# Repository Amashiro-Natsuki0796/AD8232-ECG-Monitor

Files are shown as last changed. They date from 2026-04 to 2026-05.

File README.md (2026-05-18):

# AD8232-ECG-Monitor

Real-time ECG monitoring system using AD8232 sensor, ESP8266 microcontroller, Raspberry Pi Zero/Zero W, and MHS3.5 LCD display.

# Project Background:
Originally this was my personal hobby project, and I made a simplified version to enter in a competition. However, a few days later a friend who was approaching her college entrance exam told me she had symptoms resembling panic attacks, with heart palpitations, shortness of breath, and feelings of impending doom. Since she lived alone, I worked continuously for 15 hours to add UI interaction and remote monitoring features, hoping to help her and hoping I could face my former self with a clear conscience.

## Example ECG Waveforms
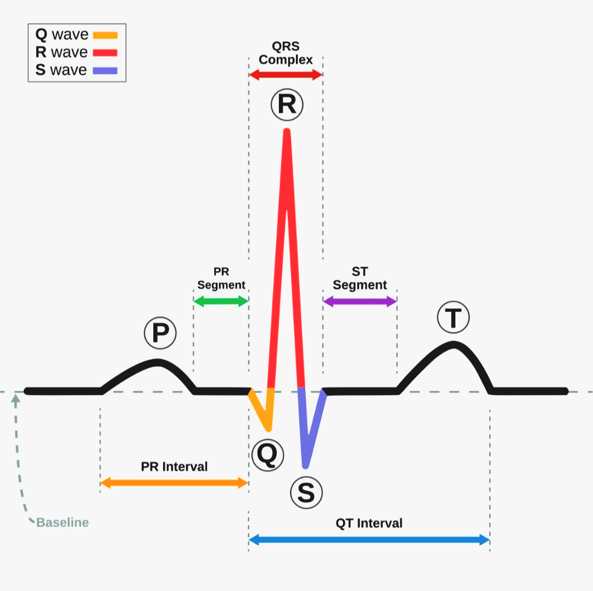
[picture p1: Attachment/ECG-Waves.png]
ECG Waves


## Hardware Components
- AD8232 ECG Sensor Module
- ESP8266 Development Board
- Raspberry Pi Zero/Zero W (Please use the Zero W version if you want to use the network remote monitoring feature)
- MHS3.5 LCD Display (480x320 resolution)
- LC filtering module (0-25V)

## Electrode Placement Diagram
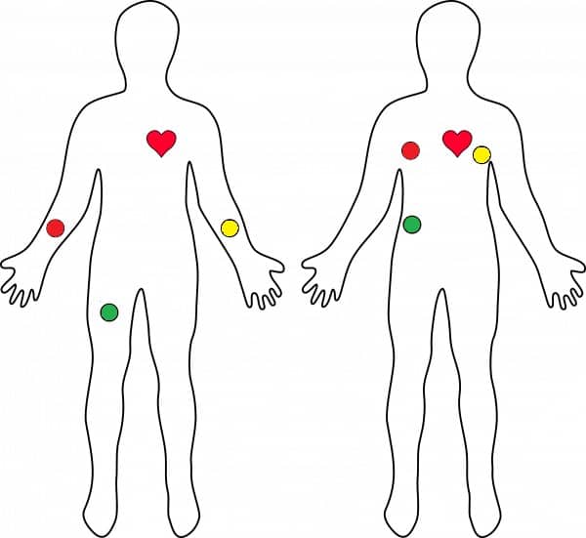
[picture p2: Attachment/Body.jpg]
Electrode Placement


## Build and Deployment Guide

### 1. ESP8266 Setup
Upload the `ESP8266.ino` file to your ESP8266 board using Arduino IDE:
- Open `ESP8266.ino` in Arduino IDE
- Select appropriate board settings for your ESP8266
- Compile and upload the program

### 1.1 Using Remote Monitoring Feature
To use the remote monitoring feature, you need to configure your Raspberry Pi to connect to your WiFi network, and register a free account at [Sakura Frp](https://www.natfrp.com) and create a TCP tunnel.

### 2. Raspberry Pi Zero Setup
Connect your Raspberry Pi Zero/Zero W to the MHS3.5 LCD display and ensure proper wiring between ESP8266 and Pi:
- Connect the TX pin of ESP8266 to the RX pin (GPIO 15) of Raspberry Pi UART
- Ensure common ground connection between ESP8266 and Raspberry Pi
- MHS3.5 LCD connects to Raspberry Pi Zero via GPIO pins
##### As shown in the diagram below:
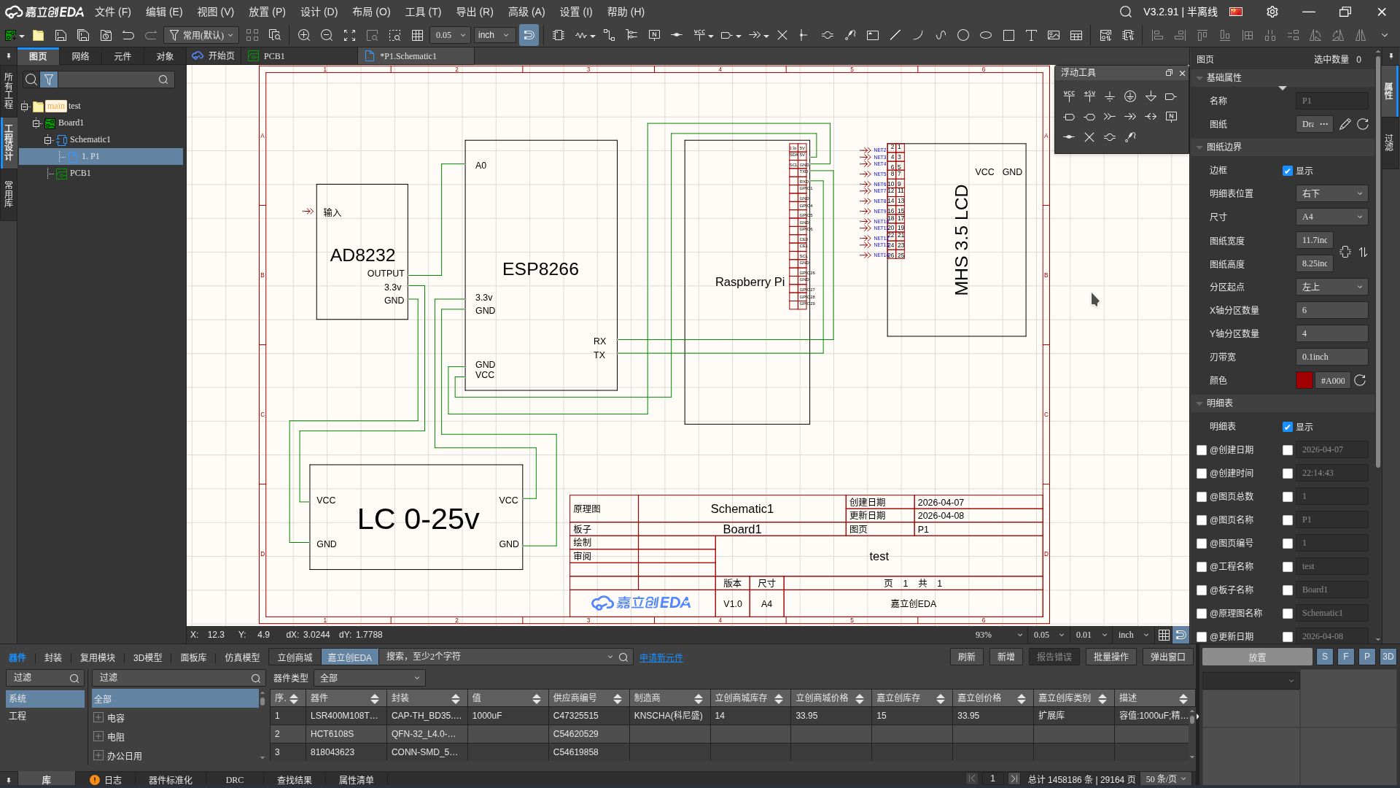
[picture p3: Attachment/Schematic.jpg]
Wiring Diagram


### 2.1 LCD Driver Installation
If using MHS3.5 LCD screen, install the corresponding drivers:
```bash
# Download LCD-show driver
git clone https://github.com/goodtft/LCD-show.git
chmod -R 755 LCD-show
cd LCD-show/
sudo ./MHS35-show
```

### 3. Environment Preparation
```bash
# Clone the repository on Target side:
git clone https://github.com/Amashiro-Natsuki0796/AD8232-ECG-Monitor.git
cd AD8232-ECG-Monitor

# Install dependencies
sudo apt-get update
sudo apt-get install build-essential nano gcc
# Configure wireless network connection
sudo raspi-config
```

### 4. Modify and Compile
```bash
# On Host side run:
cd Sakura-Frp/
./frpc
# Login to your account

# On Target side run:
cd AD8232-ECG-Monitor/
nano Main.c # Modify SERVER_IP to your IP address
make -j$(nproc)
sudo ./Main
```

### 5. Auto-start Service (Optional)
To automatically run the ECG monitor on startup:
```bash
# Copy service file to systemd
sudo cp ECG.service /etc/systemd/system/

# Enable and start the service
sudo systemctl enable ECG.service
sudo systemctl start ECG.service
```

## 3D Printed Enclosure Models
We provide 3D models for housing the electronics in a dedicated enclosure:
- Shell.STL - Main housing
- Bottom.STL - Bottom cover
- Stent.STL - Internal support structure

These SolidWorks models are located in the `Shell Model` directory and can be 3D printed to create an enclosure for the ECG monitor.

## Demonstration Video
Watch the demonstration videos to see the ECG monitor in action:

[Development Phase](Attachment/ENG.mp4)
[Demo Video](Attachment/Demo.mp4)

## Demo Screenshots
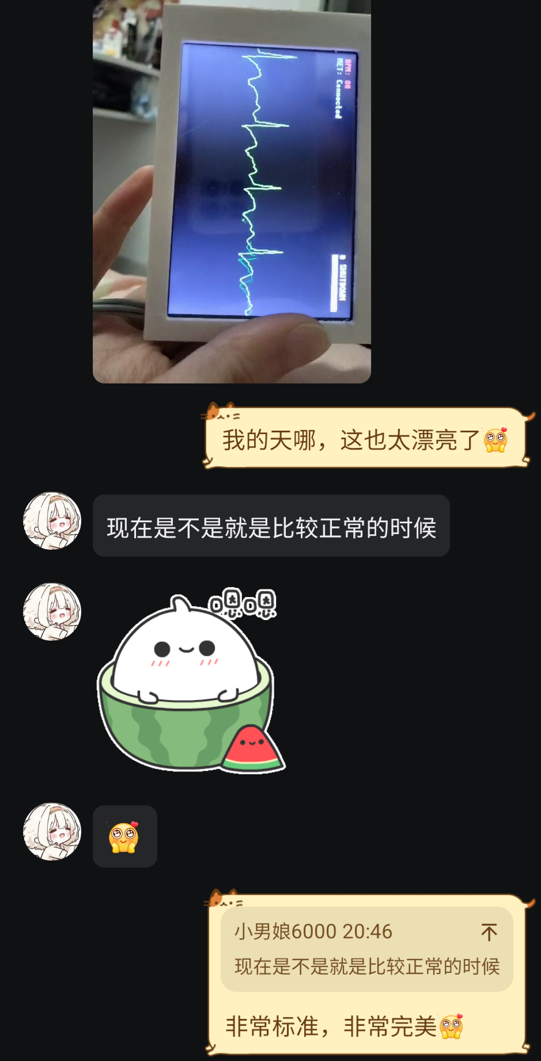
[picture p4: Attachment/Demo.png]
Log

Client

## Alternative Display Solutions
As an alternative to PC-side visualization, Python-based plotting tools are provided:

Remote monitoring: 
`Attachment/ECG_network_plotter.py`

ESP8266 serial plotting: 
`Attachment/ECG_serial_plotter.py`

Host-side simulation data sending: 
`Attachment/ECG_simulator.py`

# Disclaimer:
This project is for learning and reference purposes only and cannot be used in professional medical fields. The author does not assume any responsibility if users violate the agreement.

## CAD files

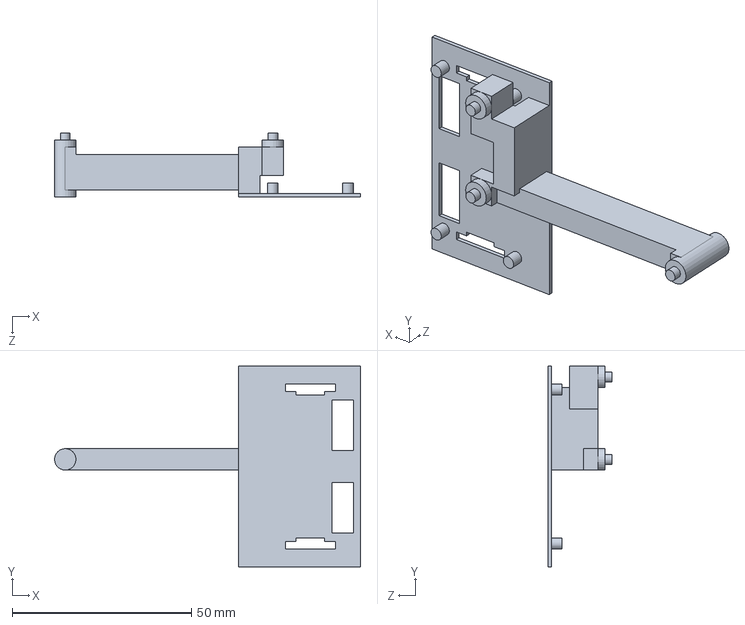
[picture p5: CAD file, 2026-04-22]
Shell Model/Stent.SLDPRT
85.4 x 56.0 x 18.0 mm

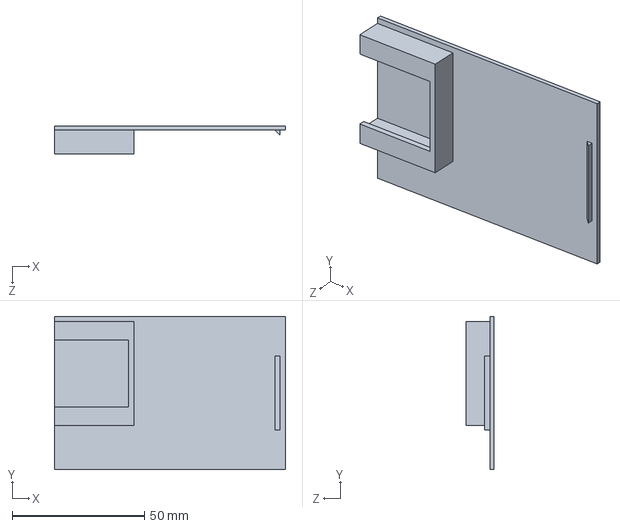
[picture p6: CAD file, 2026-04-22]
Shell Model/Bottom.SLDPRT
87.4 x 58.0 x 10.5 mm

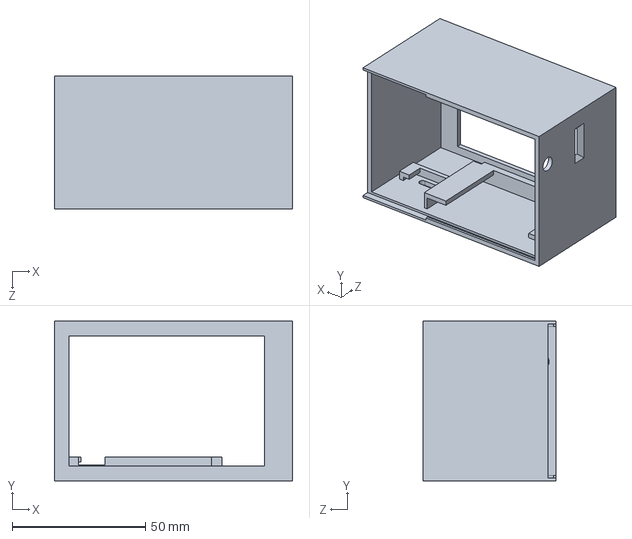
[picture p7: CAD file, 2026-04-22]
Shell Model/Shell.SLDPRT
89.4 x 60.0 x 50.0 mm

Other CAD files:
Shell Model/Bottom.STL
Shell Model/Shell.STL
Shell Model/Stent.STL

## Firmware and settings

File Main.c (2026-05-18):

#define _GNU_SOURCE
#include <stdio.h>
#include <stdlib.h>
#include <string.h>
#include <unistd.h>
#include <fcntl.h>
#include <math.h>
#include <termios.h>
#include <time.h>
#include <sys/time.h>
#include <sys/ioctl.h>
#include <sys/mman.h>
#include <sys/stat.h>
#include <linux/fb.h>
#include <errno.h>
#include <stdint.h>
#include <sched.h>
#include <sys/socket.h>
#include <netinet/in.h>
#include <arpa/inet.h>
#include <netdb.h>
#include <signal.h>
#include <linux/input.h>
#include <linux/uinput.h>

#ifndef M_PI
#define M_PI 3.14159265358979323846
#endif

#define SR 250.0
#define MAX_DP 750
#define PORT "/dev/ttyS0"
#define BR B115200
#define BS 1024

// 显示参数 - 树莓派Zero 480x320 分辨率 16bpp
#define SCREEN_WIDTH 480
#define SCREEN_HEIGHT 320
#define BYTES_PER_PIXEL 2  // 16bpp = 2 bytes per pixel

// 网络参数
#define SERVER_IP "**.***.***.***"
#define SERVER_PORT 23956
int network_socket = -1;
time_t last_connect_attempt = 0;
const int RECONNECT_INTERVAL = 5; // 重连间隔5秒

// 数据缓冲区，每0.5秒发送一次数据
#define NETWORK_BUFFER_SIZE 2048
char network_buffer[NETWORK_BUFFER_SIZE]; // 缓冲区用于存储0.5秒的数据
int buffer_pos = 0;
struct timeval last_send_time; // 使用timeval记录精确时间
double SEND_INTERVAL = 0.5; // 每0.5秒发送一次数据
int consecutive_send_failures = 0; // 连续发送失败次数
const int MAX_CONSECUTIVE_FAILURES = 3; // 最大连续失败次数后重置连接

// 触摸屏参数
#define TOUCH_DEVICE "/dev/input/event0"
int touch_fd = -1;
int paused = 0; // 暂停标志
// 关机功能相关变量
int touch_down = 0; // 触摸按下状态
struct timeval touch_start_time; // 触摸开始时间
int shutdown_triggered = 0; // 关机是否已触发

// 滤波器参数
double b_h[3], a_h[3], z_h[2];
double f_d[MAX_DP], ma_b[5];
int dc = 0, mc = 0;

// BPM计算相关变量
double last_peak_time = 0.0;
double current_heart_rate = 0.0;
double signal_peaks[50];  // 存储最近的峰值
int peak_count = 0;
double rr_intervals[50];  // 存储RR间期
int rr_count = 0;
double dynamic_threshold = 0.1;  // 动态阈值
double peak_hold = 0.0;          // 峰值保持
double last_voltage = 0.0;       // 上次电压值用于检测下降沿
int refractory_period_counter = 0; // 不应期计数器
const int REFRACTORY_PERIOD = 50;  // 不应期（采样点数）
double start_time = 0.0;           // 开始时间戳

// 函数声明
void draw_pixel(int x, int y, uint16_t color);

// framebuffer相关变量
int fb_fd = -1;
char *fb_ptr = NULL;
struct fb_var_screeninfo vinfo;
struct fb_fix_screeninfo finfo;

// 字符大小
#define CHAR_WIDTH 8
#define CHAR_HEIGHT 12

// ASCII字符字模数据 (简化版，只包含数字和基本字符)
const unsigned char font_data[96][12] = {
    {0x00,0x00,0x00,0x00,0x00,0x00,0x00,0x00,0x00,0x00,0x00,0x00}, // ' ' (32)
    {0x10,0x10,0x10,0x10,0x10,0x00,0x10,0x00,0x10,0x00,0x00,0x00}, // '!' (33)
    {0x28,0x28,0x00,0x00,0x00,0x00,0x00,0x00,0x00,0x00,0x00,0x00}, // '"' (34)
    {0x00,0x00,0x6C,0x6C,0xFE,0x6C,0x6C,0x6C,0xFE,0x6C,0x6C,0x00}, // '#' (35)
    {0x18,0x3C,0x66,0x24,0x18,0x3C,0x66,0x66,0x3C,0x18,0x00,0x00}, // '$' (36)
    {0x00,0xC6,0xCC,0x18,0x30,0x60,0xC0,0x66,0x3C,0x00,0x00,0x00}, // '%' (37)
    {0x38,0x6C,0x6C,0x38,0x76,0xDC,0xCC,0xCC,0x76,0x00,0x00,0x00}, // '&' (38)
    {0x10,0x10,0x20,0x00,0x00,0x00,0x00,0x00,0x00,0x00,0x00,0x00}, // ''' (39)
    {0x0C,0x18,0x30,0x30,0x30,0x30,0x30,0x30,0x18,0x0C,0x00,0x00}, // '(' (40)
    {0x30,0x18,0x0C,0x0C,0x0C,0x0C,0x0C,0x0C,0x18,0x30,0x00,0x00}, // ')' (41)
    {0x00,0x00,0x66,0x3C,0xFF,0x3C,0x66,0x00,0x00,0x00,0x00,0x00}, // '*' (42)
    {0x00,0x00,0x10,0x10,0x7C,0x10,0x10,0x00,0x00,0x00,0x00,0x00}, // '+' (43)
    {0x00,0x00,0x00,0x00,0x00,0x00,0x00,0x00,0x18,0x18,0x30,0x00}, // ',' (44)
    {0x00,0x00,0x00,0x00,0x7C,0x00,0x00,0x00,0x00,0x00,0x00,0x00}, // '-' (45)
    {0x00,0x00,0x00,0x00,0x00,0x00,0x00,0x00,0x18,0x18,0x00,0x00}, // '.' (46)
    {0x00,0x02,0x06,0x0C,0x18,0x30,0x60,0xC0,0x80,0x00,0x00,0x00}, // '/' (47)
    {0x38,0x6C,0xC6,0xE6,0xF6,0xDE,0xCE,0xC6,0x6C,0x38,0x00,0x00}, // '0' (48)
    {0x18,0x38,0x78,0x18,0x18,0x18,0x18,0x18,0x18,0x7E,0x00,0x00}, // '1' (49)
    {0x3C,0x66,0x06,0x06,0x0C,0x18,0x30,0x60,0x60,0x7E,0x00,0x00}, // '2' (50)
    {0x3C,0x66,0x06,0x06,0x1C,0x06,0x06,0x06,0x66,0x3C,0x00,0x00}, // '3' (51)
    {0x06,0x0E,0x1E,0x66,0x66,0x66,0x7F,0x06,0x06,0x06,0x00,0x00}, // '4' (52)
    {0x7E,0x60,0x60,0x60,0x7C,0x06,0x06,0x06,0x66,0x3C,0x00,0x00}, // '5' (53)
    {0x1C,0x30,0x60,0x60,0x7C,0x66,0x66,0x66,0x66,0x3C,0x00,0x00}, // '6' (54)
    {0x7E,0x66,0x06,0x06,0x0C,0x18,0x18,0x18,0x18,0x18,0x00,0x00}, // '7' (55)
    {0x3C,0x66,0x66,0x66,0x3C,0x66,0x66,0x66,0x66,0x3C,0x00,0x00}, // '8' (56)
    {0x3C,0x66,0x66,0x66,0x66,0x3E,0x06,0x06,0x66,0x3C,0x00,0x00}, // '9' (57)
    {0x00,0x00,0x18,0x18,0x00,0x00,0x00,0x18,0x18,0x00,0x00,0x00}, // ':' (58)
    {0x00,0x00,0x18,0x18,0x00,0x00,0x00,0x18,0x18,0x30,0x00,0x00}, // ';' (59)
    {0x0C,0x18,0x30,0x60,0xC0,0x60,0x30,0x18,0x0C,0x00,0x00,0x00}, // '<' (60)
    {0x00,0x00,0x00,0xFE,0x00,0x00,0xFE,0x00,0x00,0x00,0x00,0x00}, // '=' (61)
    {0x60,0x30,0x18,0x0C,0x06,0x0C,0x18,0x30,0x60,0x00,0x00,0x00}, // '>' (62)
    {0x3C,0x66,0x06,0x0C,0x18,0x18,0x18,0x00,0x18,0x18,0x00,0x00}, // '?' (63)
    {0x38,0x4C,0xBA,0xBA,0xB8,0xB0,0xB0,0xB0,0x6C,0x38,0x00,0x00}, // '@' (64)
    {0x10,0x38,0x6C,0xC6,0xC6,0xFE,0xC6,0xC6,0xC6,0xC6,0x00,0x00}, // 'A' (65)
    {0x7C,0x66,0x66,0x66,0x7C,0x66,0x66,0x66,0x66,0x7C,0x00,0x00}, // 'B' (66)
    {0x3C,0x66,0x60,0x60,0x60,0x60,0x60,0x60,0x66,0x3C,0x00,0x00}, // 'C' (67)
    {0x78,0x6C,0x66,0x66,0x66,0x66,0x66,0x66,0x6C,0x78,0x00,0x00}, // 'D' (68)
    {0x7E,0x60,0x60,0x60,0x7C,0x60,0x60,0x60,0x60,0x7E,0x00,0x00}, // 'E' (69)
    {0x7E,0x60,0x60,0x60,0x7C,0x60,0x60,0x60,0x60,0x60,0x00,0x00}, // 'F' (70)
    {0x3C,0x66,0x06,0x06,0x06,0x7E,0x66,0x66,0x66,0x3C,0x00,0x00}, // 'G' (71)
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
    {0x00,0x00,0x00,0x00,0x00,0x00,0x00,0x00,0x00,0x00,0x00,0x00}  // DEL (127)
};

// 函数声明
void add_to_network_buffer(double value, double timestamp);
void flush_network_buffer();
void check_and_reconnect();
int init_touchscreen();
void handle_touch_events();

// 将RGB888转换为RGB565
uint16_t rgb888_to_rgb565(int r, int g, int b) {
    r = (r >> 3) & 0x1F;  // 8位红转5位
    g = (g >> 2) & 0x3F;  // 8位绿转6位
    b = (b >> 3) & 0x1F;  // 8位蓝转5位
    return (r << 11) | (g << 5) | b;
}

// 在framebuffer上绘制字符
void draw_char(int x, int y, char c, uint16_t color) {
    if (c < 32 || c > 127) return; // 只支持ASCII 32-127
    
    int char_index = c - 32;
    
    for (int row = 0; row < CHAR_HEIGHT; row++) {
        unsigned char byte = font_data[char_index][row];
        for (int col = 0; col < 8; col++) {
            if ((byte >> (7 - col)) & 1) {
                draw_pixel(x + col, y + row, color);
            }
        }
    }
}

// 在framebuffer上绘制字符串
void draw_string(int x, int y, const char* str, uint16_t color) {
    int orig_x = x;
    while (*str) {
        if (*str == '\n') {
            y += CHAR_HEIGHT + 2;
            x = orig_x;
        } else {
            draw_char(x, y, *str, color);
            x += CHAR_WIDTH;
        }
        str++;
    }
}

// 初始化framebuffer
int init_framebuffer() {
    fb_fd = open("/dev/fb1", O_RDWR);
    if (fb_fd == -1) {
        fb_fd = open("/dev/fb0", O_RDWR);
        if (fb_fd == -1) {
            return -1;
        }
    }
    
    if (ioctl(fb_fd, FBIOGET_FSCREENINFO, &finfo)) {
        close(fb_fd);
        return -1;
    }
    
    if (ioctl(fb_fd, FBIOGET_VSCREENINFO, &vinfo)) {
        close(fb_fd);
        return -1;
    }
    
    // 映射framebuffer到内存
    fb_ptr = (char *)mmap(0, 
                         finfo.smem_len, 
                         PROT_READ | PROT_WRITE, 
                         MAP_SHARED, 
                         fb_fd, 
                         0);
    
    if (fb_ptr == (char *)-1) {
        close(fb_fd);
        return -1;
    }
    
    return 0;
}

// 初始化触摸屏
int init_touchscreen() {
    touch_fd = open(TOUCH_DEVICE, O_RDONLY | O_NONBLOCK);
    if (touch_fd < 0) {
        return -1;
    }
    return 0;
}

// 处理触摸事件
void handle_touch_events() {
    if (touch_fd < 0) {
        return;
    }
    
    // Linux输入事件结构体
    struct input_event ev;
    ssize_t n;
    
    // 读取所有可用的触摸事件
    while ((n = read(touch_fd, &ev, sizeof(struct input_event))) > 0) {
        // 检查是否是按键事件（按下或释放）
        if (ev.type == EV_KEY && ev.code == BTN_TOUCH) {
            if (ev.value == 1) { // 按下触摸屏
                touch_down = 1;
                gettimeofday(&touch_start_time, NULL); // 记录按下时间
                shutdown_triggered = 0; // 重置关机触发状态
            } else if (ev.value == 0) { // 抬起触摸屏
                touch_down = 0;
                // 检查触摸持续时间，如果小于3秒则切换暂停状态
                struct timeval current_time;
                gettimeofday(&current_time, NULL);
                double elapsed = (current_time.tv_sec - touch_start_time.tv_sec) + 
                                (current_time.tv_usec - touch_start_time.tv_usec) / 1000000.0;
                
                // 如果触摸时间少于0.3秒且未触发关机，则切换暂停状态
                if (elapsed < 0.3 && !shutdown_triggered) {
                    paused = !paused; // 切换暂停状态
                }
            }
        }
    }
}

// 检查长按是否需要关机
void check_long_press_shutdown() {
    if (touch_down && !shutdown_triggered) {
        struct timeval current_time;
        gettimeofday(&current_time, NULL);
        
        double elapsed = (current_time.tv_sec - touch_start_time.tv_sec) + 
                        (current_time.tv_usec - touch_start_time.tv_usec) / 1000000.0;
        
        if (elapsed >= 3.0) { // 长按3秒触发关机
            shutdown_triggered = 1;
            system("sudo shutdown -h now"); // 执行关机命令
        }
    }
}

// 绘制关机进度条
void draw_shutdown_progress() {
    struct timeval current_time;
    gettimeofday(&current_time, NULL);
    
    double elapsed = 0;
    int is_counting = 0;
    
    // 如果正在触摸且未触发关机，则计算长按时间
    if (touch_down && !shutdown_triggered) {
        elapsed = (current_time.tv_sec - touch_start_time.tv_sec) + 
                (current_time.tv_usec - touch_start_time.tv_usec) / 1000000.0;
        is_counting = 1;
    }
    
    // 在右上角绘制进度条，与NET状态底部对齐
    int bar_width = (int)(fmin(elapsed / 3.0, 1.0) * 100); // 最大宽度100像素
    int bar_height = 10; // 高度10像素
    int bar_x = SCREEN_WIDTH - 110; // 右边距110像素
    int bar_y = 25; // 上边距25像素，与NET状态Y坐标相同，这样底部对齐（NET状态高度约12像素，进度条高度10像素）
    
    // 绘制进度条背景（灰色）
    uint16_t gray_color = rgb888_to_rgb565(128, 128, 128);
    for (int y = bar_y; y < bar_y + bar_height; y++) {
        for (int x = bar_x; x < bar_x + 100; x++) {
            draw_pixel(x, y, gray_color);
        }
    }
    
    // 绘制进度（紫色）
    uint16_t purple_color = rgb888_to_rgb565(128, 0, 128);
    for (int y = bar_y; y < bar_y + bar_height; y++) {
        for (int x = bar_x; x < bar_x + bar_width; x++) {
            if (is_counting) { // 只有在计时过程中才显示进度
                draw_pixel(x, y, purple_color);
            }
        }
    }
    
    // 绘制"Shutdown"文字
    uint16_t white_color = rgb888_to_rgb565(255, 255, 255);
    draw_string(bar_x, bar_y - 15, "# SHUTDOWN", white_color); // 文字位置也要相应调整
}

// 清屏为黑色
void clear_screen() {
    if (fb_ptr && (vinfo.xres * vinfo.yres * BYTES_PER_PIXEL <= finfo.smem_len)) {
        memset(fb_ptr, 0, vinfo.xres * vinfo.yres * BYTES_PER_PIXEL);
    }
}

// 隐藏光标
void hide_cursor() {
    system("setterm -cursor off 2>/dev/null || true");
}

// 显示光标
void show_cursor() {
    system("setterm -cursor on 2>/dev/null || true");
}

// 在framebuffer上绘制像素点
void draw_pixel(int x, int y, uint16_t color) {
    if (x >= 0 && (unsigned int)x < vinfo.xres && y >= 0 && (unsigned int)y < vinfo.yres) {
        long location = (x + vinfo.xoffset) * BYTES_PER_PIXEL + (y + vinfo.yoffset) * finfo.line_length;
        *(uint16_t*)(fb_ptr + location) = color;
    }
}

// 使用Bresenham算法绘制直线
void draw_line(int x0, int y0, int x1, int y1, uint16_t color) {
    int dx = abs(x1-x0), sx = x0<x1 ? 1 : -1;
    int dy = abs(y1-y0), sy = y0<y1 ? 1 : -1; 
    int err = (dx>dy ? dx : -dy)/2, e2;
 
    for(;;){
        draw_pixel(x0, y0, color);
        if (x0==x1 && y0==y1) break;
        e2 = err;
        if (e2 >-dx) { err -= dy; x0 += sx; }
        if (e2 < dy) { err += dx; y0 += sy; }
    }
}

// 绘制ECG波形到framebuffer
void draw_ecg_waveform() {
    if (!fb_ptr) return;
    
    // 只清除波形区域，保持背景黑色
    // 计算波形显示区域的行数，仅清空这部分
    int start_row = 0;
    unsigned int end_row = vinfo.yres;
    
    // 清除波形区域（设为黑色）
    for (unsigned int y = start_row; y < end_row; y++) {
        for (unsigned int x = 0; x < vinfo.xres; x++) {
            long location = (x + vinfo.xoffset) * BYTES_PER_PIXEL + (y + vinfo.yoffset) * finfo.line_length;
            if (location < (long)finfo.smem_len) {
                *(uint16_t*)(fb_ptr + location) = 0x0000; // 黑色
            }
        }
    }

    if (dc > 1) {
        uint16_t green_color = rgb888_to_rgb565(0, 255, 0);  // 绿色
        
        int ds = (dc > MAX_DP) ? dc - MAX_DP : 0;
        int dco = dc - ds;
        
        if (dco > 1) {
            double dd[MAX_DP];
            for (int i = ds; i < dc; i++) dd[i - ds] = f_d[i];
            
            double min_y = dd[0], max_y = dd[0];
            for (int i = 0; i < dco; i++) {
                if (dd[i] < min_y) min_y = dd[i];
                if (dd[i] > max_y) max_y = dd[i];
            }
            
            double cy = (min_y + max_y) / 2.0;
            double ry = max_y - min_y;
            if (ry < 2.0) ry = 2.0;
            
            double ymin = cy - ry;
            double ymax = cy + ry;
            
            // 绘制波形线
            for (int i = 1; i < dco; i++) {
                int x1 = (i - 1) * vinfo.xres / dco;
                int x2 = i * vinfo.xres / dco;
                int y1 = (int)((dd[i-1] - ymin) / (ymax - ymin) * vinfo.yres);
                int y2 = (int)((dd[i] - ymin) / (ymax - ymin) * vinfo.yres);
                
                // 转换Y坐标（因为framebuffer的原点在左上角，而我们的数据是正向的）
                y1 = vinfo.yres - y1;
                y2 = vinfo.yres - y2;
                
                draw_line(x1, y1, x2, y2, green_color);
            }
        }
    }
    
    // 绘制BPM数值
    uint16_t red_color = rgb888_to_rgb565(255, 0, 0);  // 红色
    char bpm_text[20];
    snprintf(bpm_text, sizeof(bpm_text), "BPM: %.0f", current_heart_rate);
    draw_string(10, 10, bpm_text, red_color);  // 在左上角显示BPM
    
    // 绘制网络连接状态
    uint16_t net_status_color;
    char net_status_text[30];
    if (network_socket >= 0) {
        net_status_color = rgb888_to_rgb565(173, 216, 230);  // 浅蓝色
        strcpy(net_status_text, "NET: Connected");
    } else {
        net_status_color = rgb888_to_rgb565(255, 165, 0);     // 橙色
        strcpy(net_status_text, "NET: Disconnected");
    }
    draw_string(10, 25, net_status_text, net_status_color);  // 在BPM下方显示网络状态
}

void init_filter() {
    double nq = 0.5 * SR, Wn = 0.5 / nq;
    double a = tan(M_PI * Wn), as = a * a, f = as + 2*a + 1;
    b_h[0] = 1.0/f; b_h[1] = -2.0/f; b_h[2] = 1.0/f;
    a_h[0] = 1.0; a_h[1] = (2.0 * (as - 1))/f; a_h[2] = (as - 2*a + 1)/f;
    z_h[0] = 0.0; z_h[1] = 0.0;
}

double filter(double in) {
    double out = b_h[0] * in + z_h[0];
    z_h[0] = b_h[1] * in - a_h[1] * out + z_h[1];
    z_h[1] = b_h[2] * in - a_h[2] * out;
    return out;
}

int open_port(const char* p) {
    int fd = open(p, O_RDWR | O_NOCTTY | O_SYNC);
    if (fd < 0) { 
        return -1; 
    }
    
    struct termios tty;
    memset(&tty, 0, sizeof(tty));
    if (tcgetattr(fd, &tty) != 0) { 
        close(fd);
        return -1; 
    }
    
    cfsetospeed(&tty, BR);
    cfsetispeed(&tty, BR);
    tty.c_cflag |= (CLOCAL | CREAD);
    tty.c_cflag &= ~CSIZE;
    tty.c_cflag |= CS8;
    tty.c_cflag &= ~PARENB;
    tty.c_cflag &= ~CSTOPB;
    #ifdef CRTSCTS
    tty.c_cflag &= ~CRTSCTS;
    #else
    tty.c_cflag &= ~020000000000;
    #endif
    tty.c_iflag &= ~(IGNBRK | BRKINT | PARMRK | ISTRIP | INLCR | IGNCR | ICRNL | IXON);
    tty.c_lflag &= ~(ECHO | ECHONL | ICANON | ISIG | IEXTEN);
    tty.c_oflag &= ~OPOST;
    tty.c_cc[VMIN] = 1;
    tty.c_cc[VTIME] = 1;
    
    if (tcsetattr(fd, TCSANOW, &tty) != 0) { 
        close(fd);
        return -1; 
    }
    return fd;
}
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
int main(__attribute__((unused)) int argc, __attribute__((unused)) char *argv[]) {
    // 忽略SIGPIPE信号，防止因对端关闭连接而导致程序终止
    signal(SIGPIPE, SIG_IGN);
    
    // 隐藏光标
    hide_cursor();
    
    // 初始化framebuffer
    if (init_framebuffer() < 0) {
        return -1;
    }
    
    // 初始化网络参数
    last_connect_attempt = time(NULL) - RECONNECT_INTERVAL; // 立即尝试连接
    gettimeofday(&last_send_time, NULL); // 初始化发送时间
    buffer_pos = 0; // 初始化缓冲区位置
    
    // 初始化触摸屏
    init_touchscreen();
    
    // 清屏
    clear_screen();
    
    // 初始化BPM相关变量
    last_peak_time = 0.0;
    current_heart_rate = 0.0;
    peak_count = 0;
    rr_count = 0;
    dynamic_threshold = 0.1;
    peak_hold = 0.0;
    last_voltage = 0.0;
    refractory_period_counter = 0;
    start_time = time(NULL);  // 记录开始时间
    
    init_filter();

    int sfd = open_port(PORT);

    char buf[BS];
    int bp = 0;

    while (1) {
        // 检查并维护网络连接
        check_and_reconnect();
        
        // 处理触摸事件
        handle_touch_events();
        
        // 检查长按是否需要关机
        check_long_press_shutdown();
        
        int br = read(sfd, buf + bp, sizeof(buf) - bp - 1);
        if (br > 0) {
            bp += br;
            
            int ls = 0;
            for (int i = 0; i < bp; i++) {
                if (buf[i] == '\n' || buf[i] == '\r') {
                    buf[i] = '\0';
                    char *ep;
                    double rv = strtod(buf + ls, &ep);
                    
                    if (ep != buf + ls) {
                        double v = rv * 3.3 / 1023.0;
                        double fv = filter(v);
                        
                        if (mc < 5) ma_b[mc++] = fv;
                        else {
                            for (int j = 0; j < 4; j++) ma_b[j] = ma_b[j+1];
                            ma_b[4] = fv;
                        }
                        
                        double sm = 0.0;
                        for (int j = 0; j < mc; j++) sm += ma_b[j];
                        double ffv = sm / mc;
                        
                        if (dc < MAX_DP) f_d[dc] = ffv;
                        else {
                            for (int j = 0; j < MAX_DP - 1; j++) f_d[j] = f_d[j+1];
                            f_d[MAX_DP - 1] = ffv;
                        }
                        
                        if (dc < MAX_DP) dc++;
                        struct timeval tv;
                        gettimeofday(&tv, NULL);
                        double current_time = (double)(tv.tv_sec - start_time) + (double)tv.tv_usec / 1000000.0;
                        detect_peak(ffv, current_time);
                        
                        // 将原始ADC值和时间戳添加到网络缓冲区（不受暂停状态影响）
                        add_to_network_buffer(rv, current_time);
                    }
                    
                    ls = i + 1;
                }
            }
            
            if (ls < bp) {
                memmove(buf, buf + ls, bp - ls);
                bp = bp - ls;
            } else bp = 0;
        }
        
        // 仅在非暂停状态下绘制波形
        if (!paused) {
            draw_ecg_waveform();
        }
        
        // 绘制关机进度条（无论是否暂停都显示）
        draw_shutdown_progress();
        
        usleep(10000); // 休眠10ms
    }

    // 清理资源
    if (fb_ptr) {
        munmap(fb_ptr, finfo.smem_len);
    }
    if (fb_fd >= 0) {
        close(fb_fd);
    }
    
    // 关闭网络连接前，发送剩余的数据
    if (network_socket >= 0) {
        if (buffer_pos > 0) {
            flush_network_buffer();  // 发送缓冲区剩余数据
        }
        close(network_socket);
    }
    
    // 关闭触摸屏设备
    if (touch_fd >= 0) {
        close(touch_fd);
    }
    
    // 恢复光标
    show_cursor();
    
    if(sfd >= 0) {
        close(sfd);
    }
    
    return 0;
}

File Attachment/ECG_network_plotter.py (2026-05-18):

#!/usr/bin/env python3
"""
ECG TCP接收器和绘图器 - 实时绘制ECG数据
"""
import sys, socket, json, threading, queue, numpy as np
from PyQt5.QtWidgets import QApplication, QMainWindow, QWidget, QVBoxLayout, QHBoxLayout, QLabel, QPushButton
from PyQt5.QtCore import QTimer
import pyqtgraph as pg
from scipy import signal
from datetime import datetime
import time, os

class ECGDataReceiver:
    def __init__(self, host='0.0.0.0', port=8888, data_queue=None):
        self.host, self.port, self.socket, self.running, self.data_queue = host, port, None, False, data_queue
        
    def start_server(self):
        try:
            self.socket = socket.socket(socket.AF_INET, socket.SOCK_STREAM)
            self.socket.setsockopt(socket.SOL_SOCKET, socket.SO_REUSEADDR, 1)
            self.socket.bind((self.host, self.port))
            self.socket.listen(1)
            self.running = True
            print(f"ECG监听于 {self.host}:{self.port}")
            
            while self.running:
                try:
                    conn, addr = self.socket.accept()
                    print(f"连接 {addr}")
                    threading.Thread(target=self.handle_client, args=(conn, addr), daemon=True).start()
                except socket.error as e:
                    if self.running: print(f"套接字错误: {e}")
        except Exception as e: print(f"服务器错误: {e}")
        finally:
            if self.socket: self.socket.close()
    
    def handle_client(self, conn, addr):
        try:
            buffer = ""
            while self.running:
                data = conn.recv(4096).decode('utf-8')
                if not data: break
                buffer += data
                while '\n' in buffer:
                    line, buffer = buffer.split('\n', 1)
                    line = line.strip()
                    if line:
                        try:
                            ecg_data = json.loads(line)
                            self.process_ecg_data(ecg_data, addr)
                        except json.JSONDecodeError:
                            continue
        except: pass
        finally:
            conn.close()
    
    def process_ecg_data(self, data, addr):
        ecg_value = data.get('ecg_value', 0)
        if self.data_queue:
            self.data_queue.put({'ecg_value': ecg_value})
    
    def stop_server(self):
        self.running = False
        if self.socket: self.socket.close()



class NetworkECGPlotter(QMainWindow):
    def __init__(self, host='localhost', port=8888):
        super().__init__()
        self.host, self.port = host, port
        self.data_queue = queue.Queue()
        self.receiver = ECGDataReceiver(data_queue=self.data_queue)
        
        # 初始化处理参数
        self.SAMPLE_RATE, nyquist = 250.0, 0.5 * 250.0
        self.b_high, self.a_high = signal.butter(2, 0.5/nyquist, btype='high')
        self.zi_high = signal.lfilter_zi(self.b_high, self.a_high) * 0.0
        self.filtered_data, self.signal_peaks, self.ma_buffer = [], [], []
        self.last_peak_time, self.current_heart_rate, self.rr_intervals = 0, 0, []
        self.threshold_factor, self.dynamic_threshold, self.peak_hold = 0.6, 0.2, 0.0
        self.sample_interval = 1.0 / self.SAMPLE_RATE
        
        # 异常检测参数
        self.no_pqrst_detected, self.vfib_detected, self.alarm_active, self.last_alarm_time = False, False, False, 0
        self.alarm_cooldown, self.delayed_alarm_duration, self.normal_reset_delay = 5, 10, 5  # 报警间隔5秒, 延迟警报10秒, 重置延迟5秒
        
        # 延迟警报参数
        self.arrhythmia_start_times, self.arrhythmia_accumulated_times, self.reset_start_times = {
            'no_pqrst': None,
            'vfib': None
        }, {
            'no_pqrst': 0,
            'vfib': 0
        }, {}
        
        # GUI设置
        central_widget = QWidget()
        layout = QVBoxLayout()
        central_widget.setLayout(layout)
        self.setCentralWidget(central_widget)
        
        # 控件区域
        self.control_panel = QWidget()
        self.control_panel.setStyleSheet("background-color: lightgray;")
        control_layout = QHBoxLayout()
        self.control_panel.setLayout(control_layout)
        
        self.hr_label = QLabel("HR: --")
        self.hr_label.setStyleSheet("color: red; font-size: 16px; font-weight: bold;")
        control_layout.addWidget(self.hr_label)
        
        self.alert_label = QLabel("状态: 正常")
        self.alert_label.setStyleSheet("color: blue; font-size: 16px;")
        control_layout.addWidget(self.alert_label)
        
        self.alert_toggle_button = QPushButton("关闭警报")
        self.alert_toggle_button.setStyleSheet("background-color: orange; color: white; font-weight: bold;")
        self.alert_toggle_button.clicked.connect(self.toggle_alerts)
        control_layout.addWidget(self.alert_toggle_button)
        
        layout.addWidget(self.control_panel)
        
        # 绘图组件
        self.plot_widget = pg.PlotWidget()
        self.plot_widget.setBackground('black')
        self.plot_widget.showGrid(x=True, y=True, alpha=0.3)
        self.curve = self.plot_widget.plot(pen=pg.mkPen(color=(0, 255, 0), width=1))  # 绿色心电波形线
        layout.addWidget(self.plot_widget)
        
        self.alerts_enabled = True
        self.start_tcp_server()
        self.timer = QTimer()
        self.timer.timeout.connect(self.update)
        self.timer.start(1)  # 每毫秒更新一次
    
    def start_tcp_server(self):
        threading.Thread(target=self.receiver.start_server, daemon=True).start()
    
    def update(self):
        # 处理队列数据
        while not self.data_queue.empty():
            try:
                item = self.data_queue.get_nowait()
                raw_value = float(item['ecg_value'])
                self.process_ecg_sample(raw_value)
            except queue.Empty: break
        
        # 更新绘图
        display_data = self.filtered_data[-1000:] if len(self.filtered_data) >= 1000 else self.filtered_data
        if len(display_data) > 0:
            y = np.array(display_data)
            x = np.arange(len(y))
            
            min_y, max_y = np.min(y), np.max(y)
            center_y, range_y = (min_y + max_y) / 2, max(max_y - min_y, 2)
            self.plot_widget.setYRange(center_y - range_y, center_y + range_y)
            
            self.curve.setData(x, y)
            self.plot_widget.setXRange(max(0, len(y)-1000), max(1000, len(y)), padding=0)
        
        # 检测异常并更新UI
        self.detect_arrhythmias()
        self.hr_label.setText(f"HR: {self.current_heart_rate:.0f}")
        
        # 检查异常状态并计算持续时间
        current_time = time.time()
        
        # 获取各种异常类型的累计时间
        flatline_total = self.arrhythmia_accumulated_times['no_pqrst']
        if self.arrhythmia_start_times['no_pqrst'] is not None:
            flatline_total += current_time - self.arrhythmia_start_times['no_pqrst']
        
        vfib_total = self.arrhythmia_accumulated_times['vfib']
        if self.arrhythmia_start_times['vfib'] is not None:
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

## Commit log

2026-04-22 Latest
    Organize directories and add model files
    [Bottom.SLDPRT, Bottom.STL, Shell.SLDPRT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]
2026-05-18 大版本迭代
    添加远程监护功能，重写UI交互
2026-05-18 更新 Demo.png
2026-05-18 更新 README.md
